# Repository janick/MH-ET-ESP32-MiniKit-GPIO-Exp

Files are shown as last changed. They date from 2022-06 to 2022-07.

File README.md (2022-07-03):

# GPIO Expander for MH-ET ESP32 MiniKit with On-Board A/C Supply

I'm not a board designer, so this is probably very naive, but it works for building ESPHome-based sensors
and other small IoT projects.

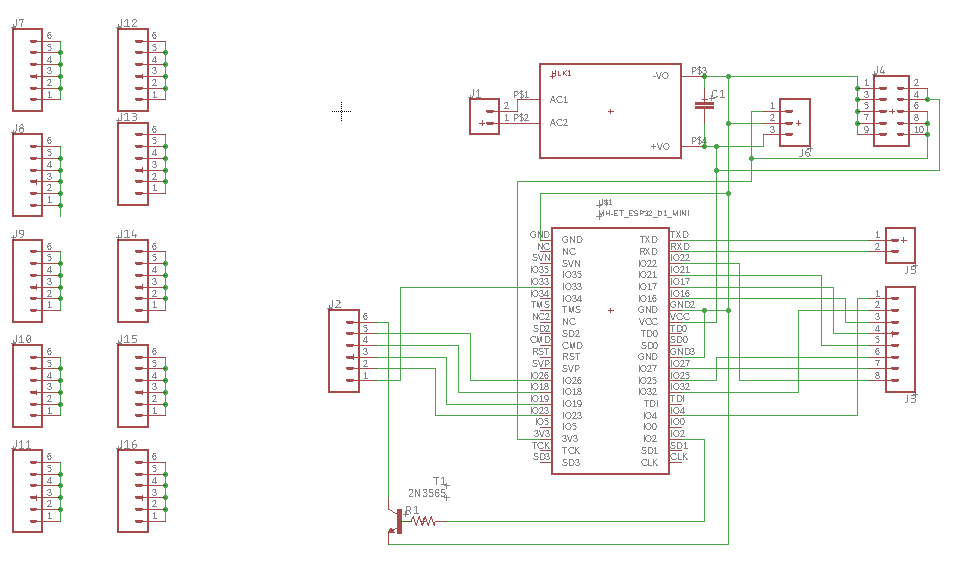
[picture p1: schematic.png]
Schematic


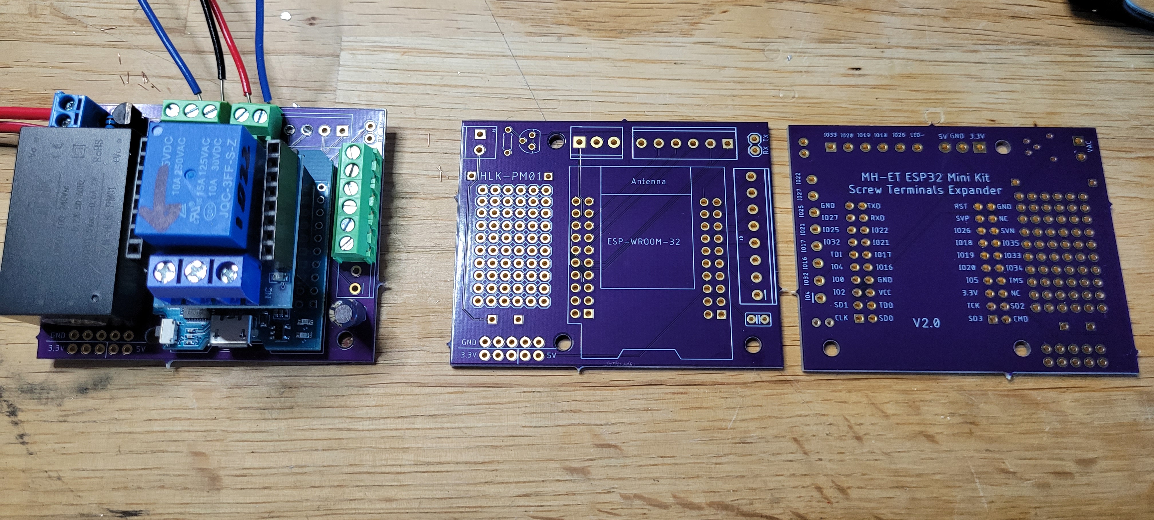
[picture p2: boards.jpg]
Boards


All the GPIOs on the "inner" rows are routed to the terminals, so there is no need to solder all
of the pins on the MiniKit all the time.
The (optional) NPN transistor (and 10k resistor) can be used to sink an external
LED that mirrors the on-board LED but that requires that GPIO2 be soldered through as it sits on
one of the "outer" rows.

Get bare boards directly from OSHPark: https://oshpark.com/shared_projects/CoKjk6w7

## Parts

* ESP-32 MiniKit: https://www.aliexpress.com/item/2251832629758482.html
* Power Supply: https://www.aliexpress.com/item/2251832424359134.html
* MiniKit Shields: https://www.aliexpress.com/item/2251832856833499.html
* Screw Terminals: https://www.aliexpress.com/item/3256802913222907.html

## Stupid Mistakes

* IO20 labels on the underside should be "IO23".
* All 6 pins in a row in the prototyping array are connected together. I should have done 3+3 so an IC could be used.
* Make the 5V and A/C traces wider
* Add protection to the power supply (https://forum.mysensors.org/topic/1607/safe-in-wall-ac-to-dc-transformers)

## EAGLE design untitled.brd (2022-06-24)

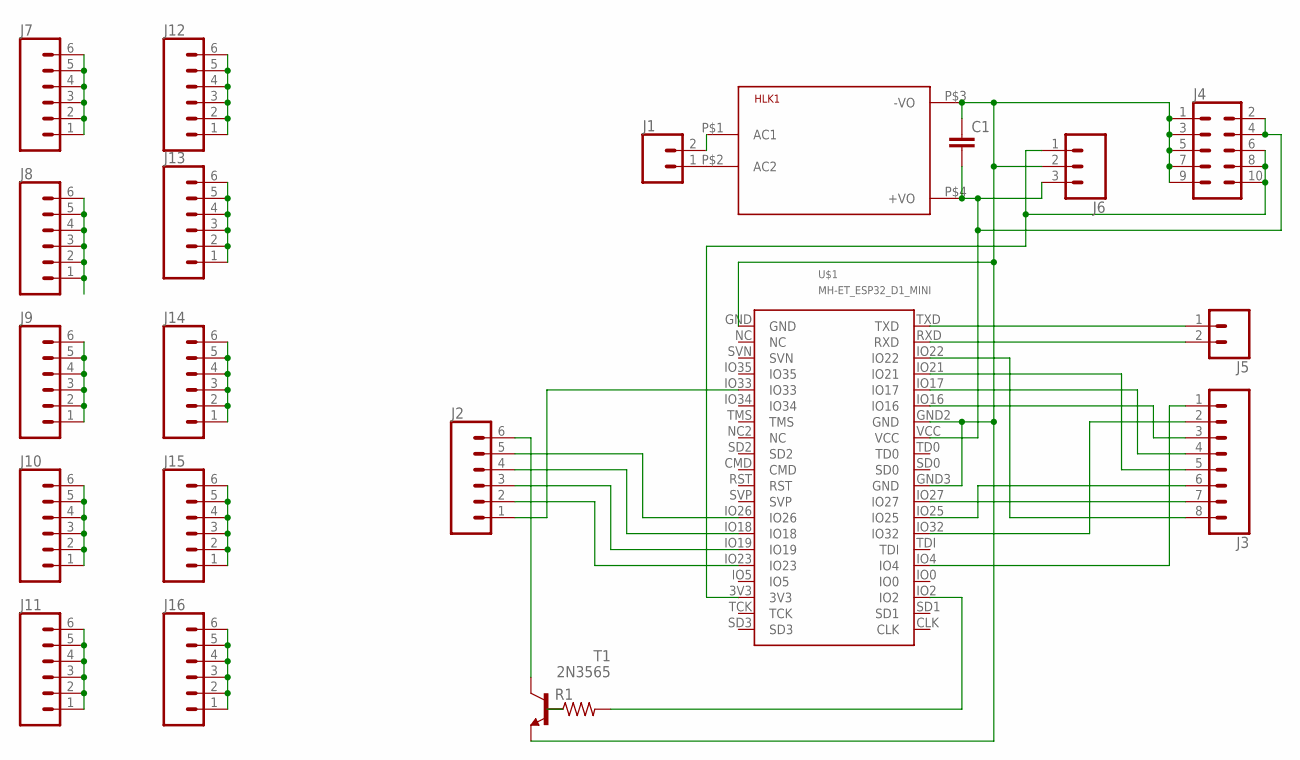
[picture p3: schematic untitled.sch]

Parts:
C1: C2.5/2; C2.5-2
HLK1: HLK-PM013W; HLK-PM01
J1: CONN_023.5MM; SCREWTERMINAL-3.5MM-2
J2: CONN_063.5MM-6; SCREWTERMINAL-3.5MM-6
J3: CONN_083.5MM-8; SCREWTERMINAL-3.5MM-8
J4: CONN_05X2NO_SILK; 2X5_NOSILK
J5: CONN_02; 1X02
J6: CONN_03SCREW; SCREWTERMINAL-3.5MM-3
J7, J8, J9, J10, J11, J12, J13, J14, J15, J16: CONN_06SILK_FEMALE_PTH; 1X06
R1: R-US_0204/5; 0204/5
T1: 2N3565; TO92
U$1: MH-ET_ESP32_D1_MINI

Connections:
GND: C1.1, HLK1.P$3 (-VO), J4.1, J4.3, J4.5, J4.7, J4.9, J6.2, T1.3 (E), U$1.GND, U$1.GND2 (GND), U$1.GND3 (GND)
unnamed: HLK1.P$2 (AC2), J1.1
unnamed: R1.1, T1.2 (B)
unnamed: J2.6, T1.1 (C)
unnamed: J2.5, U$1.IO26
unnamed: J2.4, U$1.IO18
unnamed: J2.3, U$1.IO19
unnamed: J2.2, U$1.IO23
unnamed: J2.1, U$1.IO33
unnamed: HLK1.P$1 (AC1), J1.2
unnamed: C1.2, HLK1.P$4 (+VO), J4.2, J4.4, J6.3, U$1.VCC
unnamed: J5.1, U$1.TXD
unnamed: J5.2, U$1.RXD
unnamed: J4.6, J4.8, J4.10, J6.1, U$1.3V3
unnamed: R1.2, U$1.IO2
unnamed: J3.8, U$1.IO22
unnamed: J3.6, U$1.IO25
unnamed: J3.3, U$1.IO16
unnamed: J3.4, U$1.IO17
unnamed: J3.7, U$1.IO27
unnamed: J3.5, U$1.IO21
unnamed: J3.1, U$1.IO4
unnamed: J3.2, U$1.IO32
unnamed: J7.1, J7.2, J7.3, J7.4, J7.5, J7.6
unnamed: J8.1, J8.2, J8.3, J8.4, J8.5, J8.6
unnamed: J9.1, J9.2, J9.3, J9.4, J9.5, J9.6
unnamed: J10.1, J10.2, J10.3, J10.4, J10.5, J10.6
unnamed: J11.1, J11.2, J11.3, J11.4, J11.5, J11.6
unnamed: J12.1, J12.2, J12.3, J12.4, J12.5, J12.6
unnamed: J13.1, J13.2, J13.3, J13.4, J13.5, J13.6
unnamed: J14.1, J14.2, J14.3, J14.4, J14.5, J14.6
unnamed: J15.1, J15.2, J15.3, J15.4, J15.5, J15.6
unnamed: J16.1, J16.2, J16.3, J16.4, J16.5, J16.6

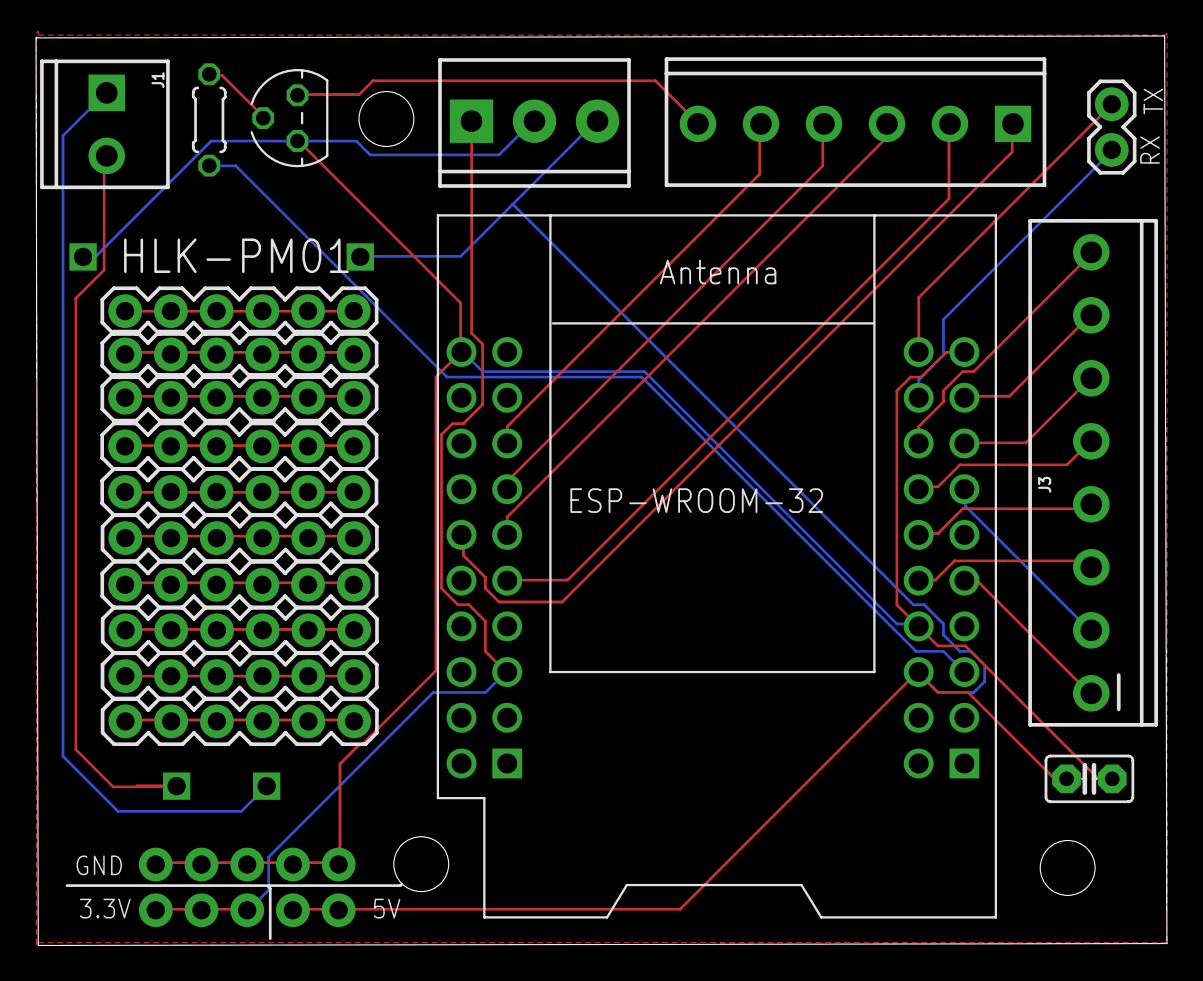
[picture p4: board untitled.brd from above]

Board: 2 copper layers, 62.8 x 50.5 mm, 21 parts (0 on the bottom side), 33 nets.

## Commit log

2022-06-24 Initial upload
    [untitled.brd, untitled.sch]
2022-06-24 Add photo of boards
2022-06-24 Point to screw terminals with correct pitch
2022-06-25 Added details on which pins on the MiniKit needs to be soldered through.
2022-06-26 A couple more stupid mistakes

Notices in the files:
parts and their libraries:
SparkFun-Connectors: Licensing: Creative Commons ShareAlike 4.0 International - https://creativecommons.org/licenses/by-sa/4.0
